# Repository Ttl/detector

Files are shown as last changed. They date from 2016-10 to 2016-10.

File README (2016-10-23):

1 MHz - 10 GHz RF power detector with USB connection.

Based on AD8319 power detector and LPC11U68 microcontroller.

Hardware:

hardware: KiCad files of the board.

Firmware:

lpc_chip_11u6x
lpc_board_detector
detector

Compile with LPCXpresso IDE.

Software:

detector.py: Main code.

ad8139cal.py: Voltage to dBm calibration table.

scalar_vna.py: Scalar network analyzer using two power sensors, two directional couplers and VNA as a signal source. VNA code can be got from: https://github.com/Ttl/vna.

analysis.py: Reflection tracking calibration and plotting the results of scalar network analyzer measurements.

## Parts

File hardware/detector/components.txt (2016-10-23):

http://www.digikey.fi/product-detail/en/analog-devices-inc/AD8319ACPZ-R7/AD8319ACPZ-R7CT-ND/1217637
http://www.digikey.fi/product-detail/en/nxp-semiconductors/LPC11U68JBD64E/568-11003-ND/4557154
http://www.digikey.fi/product-detail/en/nxp-semiconductors/2N7002P,215/568-5818-1-ND/2531105
http://www.digikey.fi/product-detail/en/fairchild-semiconductor/NC7S04P5X/NC7S04P5XCT-ND/965679
http://www.digikey.fi/product-detail/en/peregrine-semiconductor/PE42441A-Z/1046-1108-1-ND/4849858

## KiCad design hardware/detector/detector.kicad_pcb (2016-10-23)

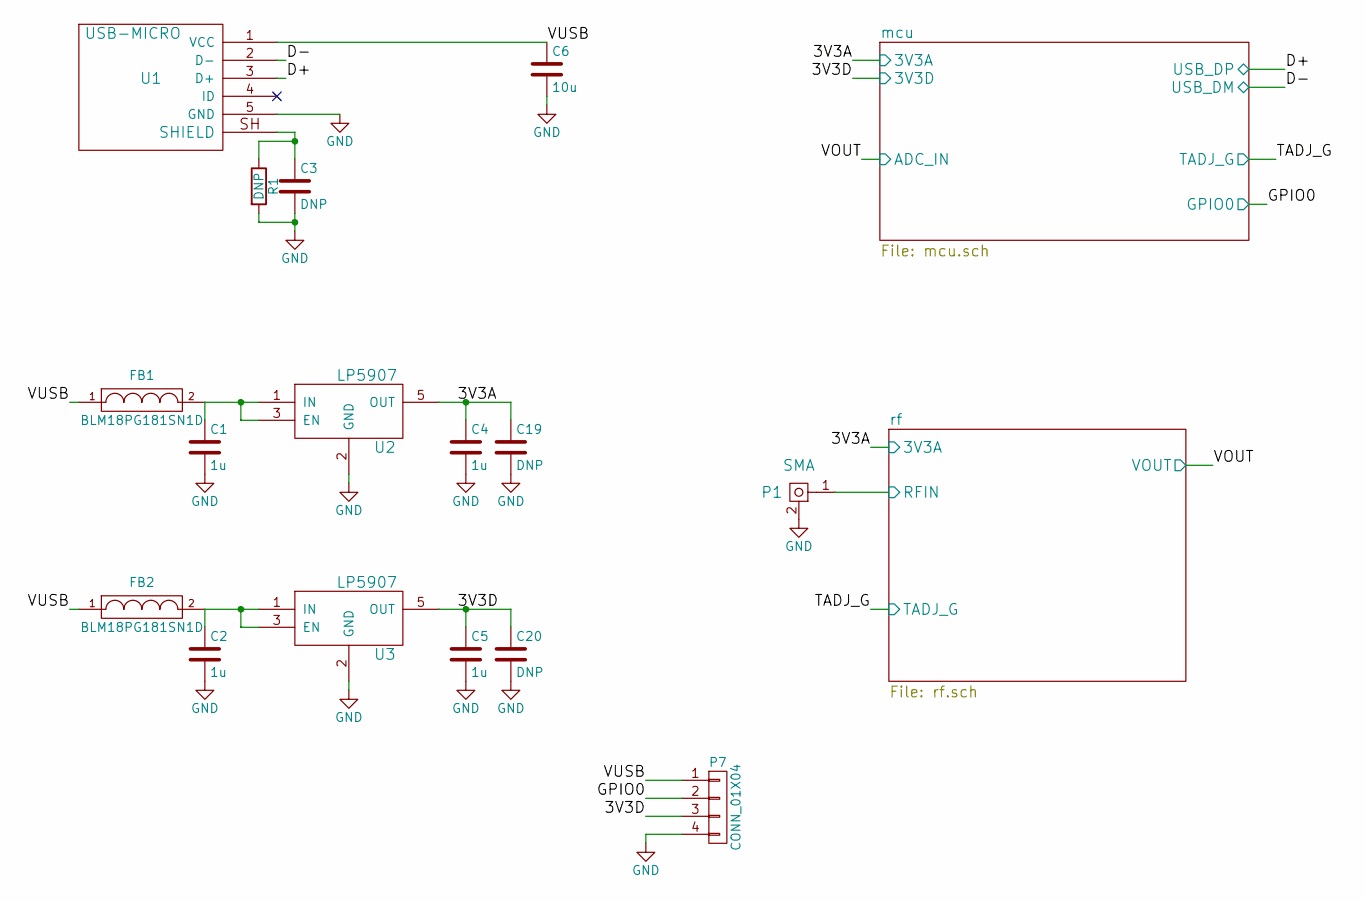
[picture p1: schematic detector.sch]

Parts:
C1, C2, C4, C5: 1u; C_0603b
C3: DNP; C_0402b
C6: 10u; C_0805b
C19, C20: DNP; C_0805b
FB1, FB2: BLM18PG181SN1D; C_0603b
P1: SMA; CONSMA003.062
P7: CONN_01X04; Pin_Header_Straight_1x04
R1: DNP; R_0402b
U1: USB-MICRO; USB_MICRO
U2, U3: LP5907; SOT-23-5

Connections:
/3V3A: C4.1, C19.1, U2.5 (OUT); also elsewhere on the board
/3V3D: C5.1, C20.1, P7.3, U3.5 (OUT); also elsewhere on the board
/D+: U1.3 (D+); also elsewhere on the board
/D-: U1.2 (D-); also elsewhere on the board
/GPIO0: P7.2; also elsewhere on the board
/VUSB: C6.1, FB1.1, FB2.1, P7.1, U1.1 (VCC)
/rf/RFIN: P1.1; also elsewhere on the board
GND: C1.2, C2.2, C3.2, C4.2, C5.2, C6.2, C19.2, C20.2, P1.2, P7.4, R1.2, U1.5 (GND), U2.2 (GND), U3.2 (GND); also elsewhere on the board
unnamed: C1.1, FB1.2, U2.1 (IN), U2.3 (EN)
unnamed: C2.1, FB2.2, U3.1 (IN), U3.3 (EN)
unnamed: C3.1, R1.1, U1.SH (SHIELD)

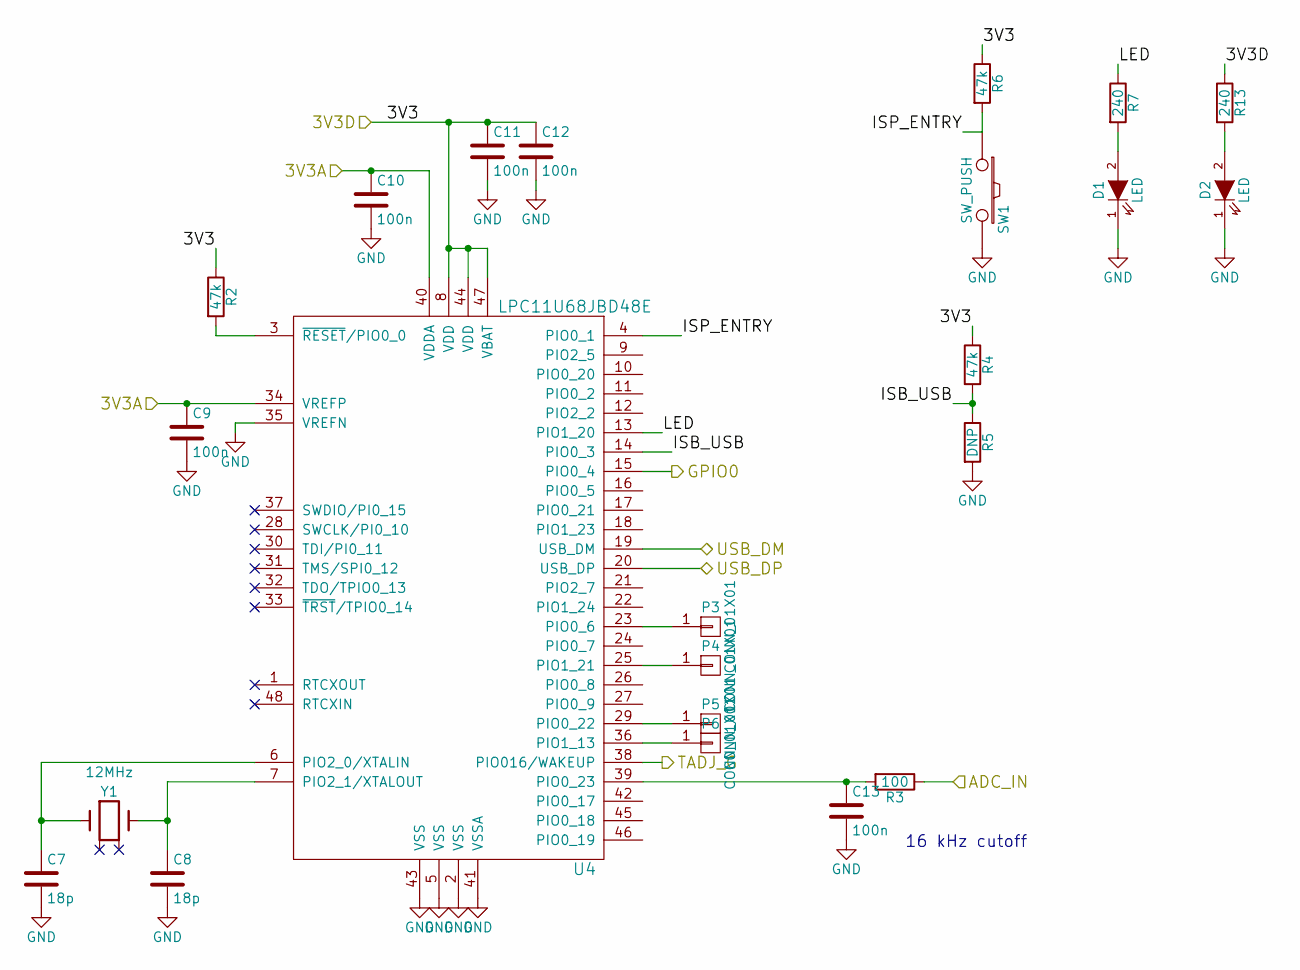
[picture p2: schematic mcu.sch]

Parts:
C7, C8: 18p; C_0402b
C9, C10, C11, C12, C13: 100n; C_0402b
D1, D2: LED; LED_0603
P3, P4, P5, P6: CONN_01X01; TP_1.00
R2, R4, R6: 47k; R_0402b
R3: 100; R_0402b
R5: DNP; R_0402b
R7, R13: 240; R_0402b
SW1: SW_PUSH; EVP-AWBA2A
U4: LPC11U68JBD48E; LQFP-48_7x7mm_Pitch0.5mm
Y1: 12MHz; XTAL_3.2x2.5

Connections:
/3V3A: C9.1, C10.1, U4.34 (VREFP), U4.40 (VDDA); also elsewhere on the board
/3V3D: C11.1, C12.1, R2.1, R4.1, R6.1, R13.1, U4.8 (VDD), U4.44 (VDD), U4.47 (VBAT); also elsewhere on the board
/D+: U4.20 (USB_DP); also elsewhere on the board
/D-: U4.19 (USB_DM); also elsewhere on the board
/GPIO0: U4.15 (PIO0_4); also elsewhere on the board
/TADJ_G: U4.38 (PIO016/WAKEUP); also elsewhere on the board
/VOUT: R3.1; also elsewhere on the board
/mcu/ISB_USB: R4.2, R5.1, U4.14 (PIO0_3)
/mcu/ISP_ENTRY: R6.2, SW1.1, U4.4 (PIO0_1)
/mcu/LED: R7.1, U4.13 (PIO1_20)
GND: C7.2, C8.2, C9.2, C10.2, C11.2, C12.2, C13.2, D1.1 (K), D2.1 (K), R5.2, SW1.2, U4.2 (VSS), U4.5 (VSS), U4.35 (VREFN), U4.41 (VSSA), U4.43 (VSS); also elsewhere on the board
unnamed: C7.1, U4.6 (PIO2_0/XTALIN), Y1.1
unnamed: C8.1, U4.7 (PIO2_1/XTALOUT), Y1.3
unnamed: C13.1, R3.2, U4.39 (PIO0_23)
unnamed: D1.2 (A), R7.2
unnamed: D2.2 (A), R13.2
unnamed: P3.1, U4.23 (PIO0_6)
unnamed: P4.1, U4.25 (PIO1_21)
unnamed: P5.1, U4.29 (PIO0_22)
unnamed: P6.1, U4.36 (PIO1_13)
unnamed: R2.2, U4.3 (~RESET~/PIO0_0)

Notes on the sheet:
16 kHz cutoff

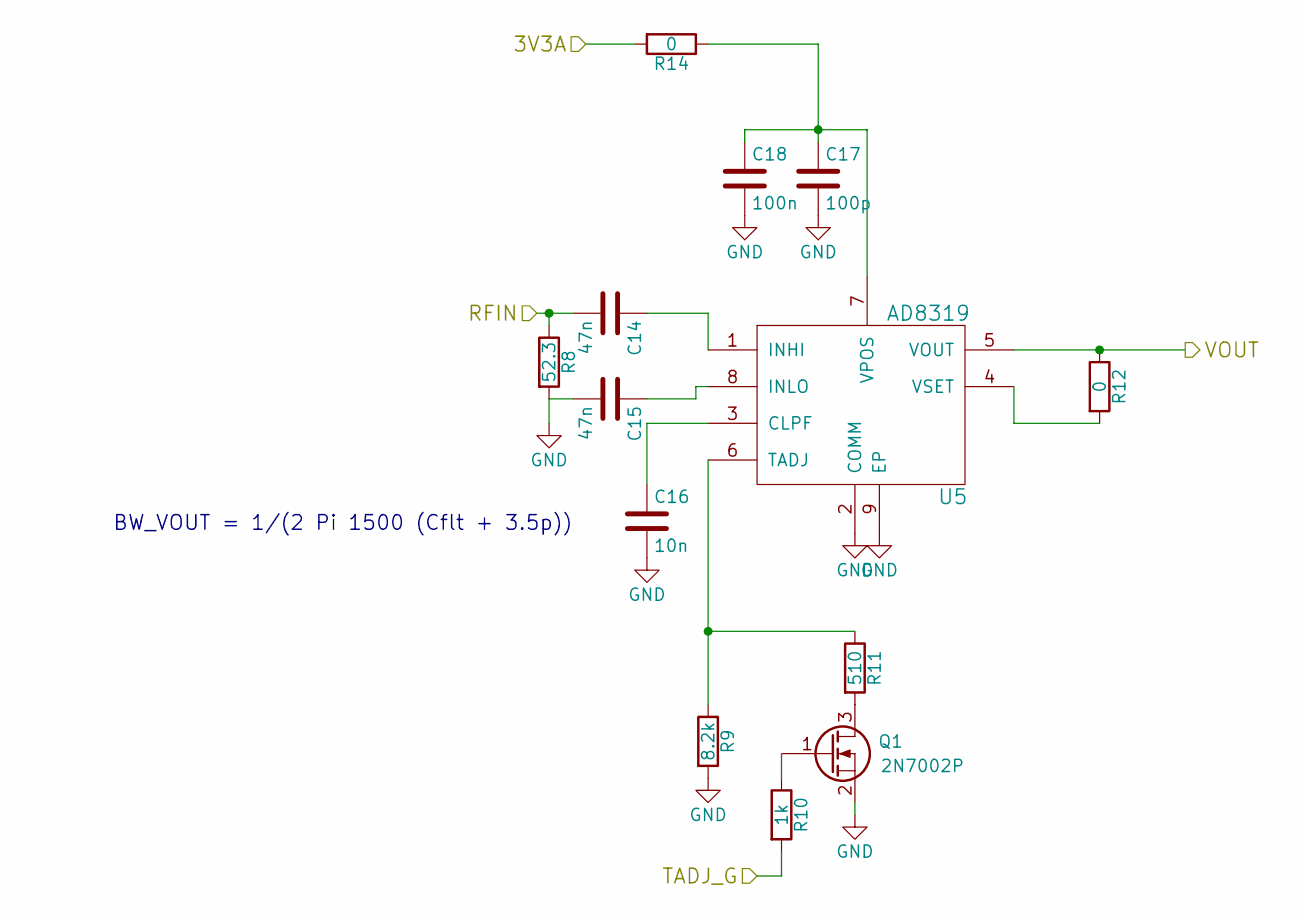
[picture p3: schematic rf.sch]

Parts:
C14, C15: 47n; C_0402b
C16: 10n; C_0402b
C17: 100p; C_0402b
C18: 100n; C_0402b
Q1: 2N7002P; SOT-23
R8: 52.3; R_0402b
R9: 8.2k; R_0402b
R10: 1k; R_0402b
R11: 510; R_0402b
R12, R14: 0; R_0402b
U5: AD8319; LFCSP-8

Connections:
/3V3A: R14.2; also elsewhere on the board
/TADJ_G: R10.2; also elsewhere on the board
/VOUT: R12.1, U5.5 (VOUT); also elsewhere on the board
/rf/RFIN: C14.2, R8.1; also elsewhere on the board
GND: C15.2, C16.2, C17.2, C18.2, Q1.2 (S), R8.2, R9.2, U5.2 (COMM), U5.9 (EP); also elsewhere on the board
unnamed: C14.1, U5.1 (INHI)
unnamed: C15.1, U5.8 (INLO)
unnamed: C16.1, U5.3 (CLPF)
unnamed: C17.1, C18.1, R14.1, U5.7 (VPOS)
unnamed: Q1.1 (G), R10.1
unnamed: Q1.3 (D), R11.2
unnamed: R9.1, R11.1, U5.6 (TADJ)
unnamed: R12.2, U5.4 (VSET)

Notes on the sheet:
BW_VOUT = 1/(2 Pi 1500 (Cflt + 3.5p))

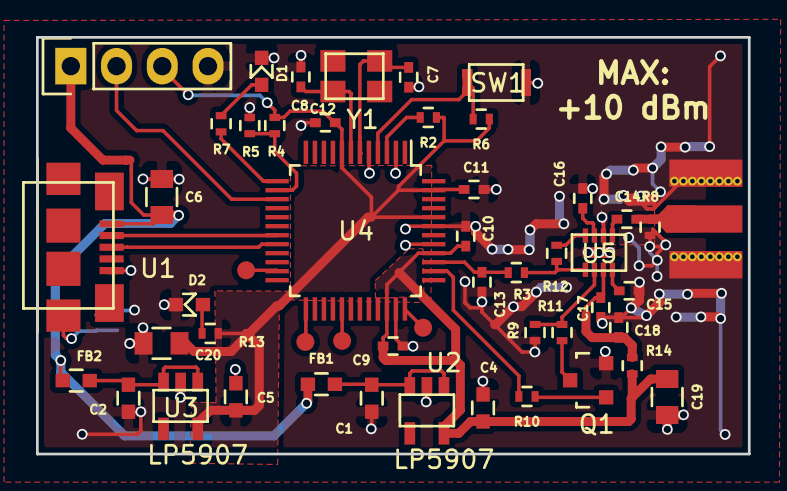
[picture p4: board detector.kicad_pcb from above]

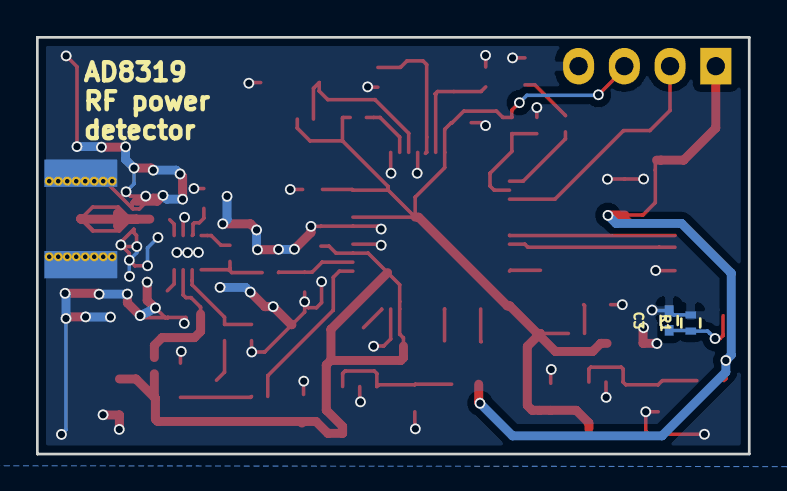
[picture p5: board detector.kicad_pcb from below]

Board: 2 copper layers, 39.5 x 23.2 mm, 52 parts (2 on the bottom side), 34 nets.

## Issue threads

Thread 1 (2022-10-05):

Update readme with compilation guide

Digitelektro, 2022-10-05:
Dear @Ttl

I built the PCB of this nice project, but I got stuck at compiling the firmware. Could you please update the readme with how to build the project, which tools needed for that etc. Or a more easy way (for me) if you could release a binary that I can flash/upload straight to the device.

Thank you!

Digitelektro, 2022-10-05:
Thank you so much! Will try it and get back to you!

Digitelektro, 2022-10-25:
I tried the firmware, it kinda works. I had to change a python script, I think the firmware version of what you sent is older, but I figured out the problem. I had to remove the packet header check from the script.
Thanks!

Closed 2022-10-25.

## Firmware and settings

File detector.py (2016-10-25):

import sys
import serial
import serial.tools.list_ports
from scipy.interpolate import interp1d
from ad8319cal import cal_table

for k in cal_table.keys():
    cal_table[k] = zip(*cal_table[k])

def v_to_dbm(v, freq):
    freq /= 1e6
    cal_freqs = sorted(cal_table.keys())
    x = []
    for f in cal_freqs:
        fx, fy = cal_table[f]
        x.append(interp1d(fy, fx, fill_value='extrapolate')(v))
    return interp1d(cal_freqs, x, fill_value='extrapolate')(freq) + 3.3 #From parallel 50 ohm termination

if __name__ == "__main__":
    if len(sys.argv) != 2:
        print "Give frequency in GHz as argument"
        exit()
    freq = float(sys.argv[1])*1e9
    if freq < 0 or freq > 10e9:
        print "Frequency out of range 0 < freq < 10"
        exit()
    ports = serial.tools.list_ports.comports()
    ser = None
    for dev, name, desc in ports:
        if 'VID:PID=1FC9:0083' in desc:
            try:
                ser = serial.Serial(
                    port=dev,
                    baudrate=1e6,
                    parity=serial.PARITY_NONE,
                    stopbits=serial.STOPBITS_TWO,
                    bytesize=serial.EIGHTBITS,
                    timeout=0.1
                )
                if not ser.isOpen():
                    raise Exception
            except:
                print 'Opening serial port {} failed.'.format(dev)
                raise
    if ser == None:
        raise Exception("Unable to find device")

    #Set T_ADJ
    if freq >= 5.3e9:
        #500 ohm if f > 5.3 GHz
        ser.write('\xf1')
    else:
        #8.2k if f < 5.3 GHz
        ser.write('\xf0')

    while True:
        try:
            x = ord(ser.read(1))
            if x != 0xFF:
                continue
            x = map(ord,ser.read(2))
            if x[0] & 0xF0 != 0x00:
                #Not synchronized
                continue
            y = ((x[0] & 0x0F) << 8) | x[1]
            print v_to_dbm(3.3*y/4095.0, freq)
        except serial.serialutil.SerialException:
            continue
        except OSError:
            continue
        except KeyboardInterrupt:
            print "Exiting"
            break

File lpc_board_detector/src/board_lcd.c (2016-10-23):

/*
 * @brief Manley 11U68 board LCD driver
 *
 * @note
 * Copyright(C) NXP Semiconductors, 2013
 * All rights reserved.
 *
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
 * @par
 * Permission to use, copy, modify, and distribute this software and its
 * documentation is hereby granted, under NXP Semiconductors' and its
 * licensor's relevant copyrights in the software, without fee, provided that it
 * is used in conjunction with NXP Semiconductors microcontrollers.  This
 * copyright, permission, and disclaimer notice must appear in all copies of
 * this code.
 */

#include "board.h"

/*****************************************************************************
 * Private types/enumerations/variables
 ****************************************************************************/

/* LCD (SPI_CS) port and pin */
#define LCDCS_PORT          0
#define LCDCS_PIN           2

/* 100nS SPI clock */
#define LCDSSP_BITRATE      (25000000)

/* SSP device mapped to LCD */
#define LCD_SSP             LPC_SSP0

/* Horizontal and vertical sizes of the LCD */
#define LCD_HORIZ_SIZE      320
#define LCD_VERT_SIZE       240

/* Flag indicating portrait or landscape orientation */
static bool orientationPortrait;
static uint8_t cont_mem;

/* Window data */
static const struct {
	uint16_t width;
	uint16_t height;
} lcd_size[] = {
	{LCD_HORIZ_SIZE, LCD_VERT_SIZE},/* Landscape mode */
	{LCD_VERT_SIZE, LCD_HORIZ_SIZE},/* Portrait mode */
};
static uint16_t line_buffer[LCD_HORIZ_SIZE + 1];
static const uint8_t InitLCD_dat[] = {
	/* Data length , Command, Data */

	/* Power control B */
	3,  0xCF, 0x00, 0xC1, 0x30,
	/* Power on sequence control */
	4,  0xED, 0x64, 0x03, 0x12, 0x81,
	/* Driver timing control A */
	3,  0xE8, 0x85, 0x10, 0x7A,
	/* Power control A */
	5,  0xCB, 0x39, 0x2C, 0x00, 0x34, 0x02,
	/* Pump ratio control */
	1,  0xF7, 0x20,
	/* Driver timing control B */
	2,  0xEA, 0x00, 0x00,
	/* Power control */
	1,  0xC0, 0x1B,
	/* Power control */
	1,  0xC1, 0x01,
	/* VCM control */
	2,  0xC5, 0x45, 0x25,
	/* VCM control2 */
	1,  0xC7, 0xB7,
	/* Memory Access Control */
	1,  0x36, 0x28,
	/*Pixel Format Set */
	1,  0x3A, 0x55,
	/*Frame Rate Control */
	2,  0xB1, 0x00, 0x1A,
	/* Display Function Control */
	2,  0xB6, 0x0A, 0x82,
	/* 3Gamma Function Disable */
	1,  0xF2, 0x00,
	/* Gamma curve selected */
	1,  0x26, 0x01,
	/* Set Gamma */
	15, 0xE0, 0x0F, 0x2A, 0x28, 0x08, 0x0E, 0x08, 0x54, 0xA9, 0x43, 0x0A, 0x0F, 0x00, 0x00, 0x00, 0x00,
	/* Set Gamma */
	15, 0xE1, 0x00, 0x15, 0x17, 0x07, 0x11, 0x06, 0x2B, 0x56, 0x3C, 0x05, 0x10, 0x0F, 0x3F, 0x3F, 0x0F,
	/* Address Column set */
	4,  0x2A, 0x00, 0x00, 0x01, 0x3F,
	/* Address Page set */
	4,  0x2B, 0x00, 0x00, 0x00, 0xEF,
	/* Sleep OUT */
	0,  0x11,
	/* Display ON */
	0,  0x29,
};

/*****************************************************************************
 * Public types/enumerations/variables
 ****************************************************************************/

/*****************************************************************************
 * Private functions
 ****************************************************************************/

/* Read data to LCD controller via SPI */
static uint16_t Board_LCD_ReadData(void)
{
	/* FIXME: Implement later */
	return 0;
}

/* Initialize SPI interface for board */
static void Board_LCDSSP_Init(void)
{
	/* Enable SSP clocking and setup SSP defaults */
	Chip_SSP_Init(LCD_SSP);

	/* 8 bits data, SPI0 mode */
	Chip_SSP_Set_Mode(LCD_SSP, SSP_MODE_MASTER);
	Chip_SSP_SetFormat(LCD_SSP, SSP_BITS_9, SSP_FRAMEFORMAT_SPI, SSP_CLOCK_CPHA0_CPOL0);

	/* Set SPI clock rate for LCD controller */
	Chip_SSP_SetBitRate(LCD_SSP, LCDSSP_BITRATE);

	/* Enable SSP */
	Chip_SSP_Enable(LCD_SSP);
}

/* Initialize the LCD Panel with startup values */
static void Board_LCDPanel_Init(void)
{
	int i, len = 0;
	for (i = 0; i < sizeof(InitLCD_dat) / sizeof(uint8_t); i += 2 + len) {
		len = InitLCD_dat[i];
		Board_LCD_WriteData(InitLCD_dat[i + 1], &InitLCD_dat[i + 2], len);
	}
}

/*****************************************************************************
 * Public functions
 ****************************************************************************/

/* Initialize LCD controller */
void Board_LCD_Init(bool portrait)
{
	volatile int i;
	/* LCD_CS (SPI_CS) mapped to PIO0_2, use GPIO to control frame */
	Chip_IOCON_PinMuxSet(LPC_IOCON, LCDCS_PORT, LCDCS_PIN,
						 (IOCON_FUNC0 | IOCON_MODE_INACT | IOCON_DIGMODE_EN));
	/* BLC mapped to PIO1_20, not used */

	/* Setup GPIO for LCD CS to output, initial LCD CS state is high */
	Chip_GPIO_SetPinDIROutput(LPC_GPIO, LCDCS_PORT, LCDCS_PIN);

	/* Initialize SPI for board LCD controller */
	Board_LCDSSP_Init();

	/* Save orientation */
	orientationPortrait = portrait;

	/* Initial LCD */
	Board_LCDPanel_Init();

	if (portrait) {	/* set to portrait mode */
		uint8_t ch = 0x8;
		Board_LCD_WriteData(0x36, &ch, 1);
	}
	for (i = 0; i < 0xFFFFF; i++) {}
}
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

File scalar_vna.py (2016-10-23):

import matplotlib.pyplot as plt
import numpy as np
from detector import *
from vna import *
import pickle

lo_set = False
lo_pll = MAX2871(2)
source_pll = MAX2871(3)

def measure(sers, device, freqs, apwr=1):
    global lo_set
    real_freqs = []
    samples = []
    for freq in freqs:
        #Set T_ADJ
        #for ser in sers:
        #    if freq >= 5.3e9:
        #        #500 ohm if f > 5.3 GHz
        #        ser.write('\xf1')
        #    else:
        #        #8.2k if f < 5.3 GHz
        #        ser.write('\xf0')

        source_freq = freq
        ref_freq = 19.2e6

        select_filter(device, source_freq)

        real_freqs.append(source_pll.freq_to_regs(source_freq, ref_freq, apwr=apwr))

        if not lo_set:
            lo_pll.freq_to_regs(source_freq, ref_freq, apwr=0)
            lo_pll.to_device(device)
            time.sleep(20e-3)
            lo_pll.to_device(device)
            lo_set = True
            source_pll.to_device(device)
            time.sleep(20e-3)
        source_pll.to_device(device)

        #print source_power(device, source_freq)

        ps = [None, None]
        for e,ser in enumerate(sers):
            ser.reset_input_buffer()
            while True:
                try:
                    x = ord(ser.read(1))
                    if x != 0xFF:
                        continue
                    x = map(ord,ser.read(2))
                    if x[0] & 0xF0 != 0x00:
                        #Not synchronized, try again
                        continue
                    y = ((x[0] & 0x0F) << 8) | x[1]
                    ps[e] = (v_to_dbm(3.3*y/4095.0, freq))
                except KeyboardInterrupt:
                    print "Exiting"
                    break
                break
        print ps[1]-ps[0],ps[0],ps[1]
        samples.append(ps[1]-ps[0])
    return real_freqs, samples

if __name__ == "__main__":

    #Find VNA to use as a source
    source = None
    device = usb.core.find(idVendor=0x1d50, idProduct=0x6099)
    if device == None:
        print "VNA not found"
        exit(0)
    print "Found VNA"

    device.set_configuration()


    #Initialize VNA
    device.ctrl_transfer(0x40, 4, 0, (1 << 0) | (1 << 2) | (0 << 3)) #Signal, PA on
    write_att(device, 0)
    select_mixer_input(device, 'rx1')
    select_port(device, 2)

    sers = []
    ports = serial.tools.list_ports.comports()
    for dev, name, desc in ports:
        if 'VID:PID=1FC9:0083' in desc:
            try:
                ser = serial.Serial(
                    port=dev,
                    baudrate=1e6,
                    parity=serial.PARITY_NONE,
                    stopbits=serial.STOPBITS_TWO,
                    bytesize=serial.EIGHTBITS,
                    timeout=0.1
                )
                if not ser.isOpen():
                    raise Exception
                sers.append(ser)
            except:
                print 'Opening serial port {} failed.'.format(dev)
                raise
    if len(sers) < 2:
        raise Exception("Unable to find power detectors. Found {}.".format(len(sers)))

    freqs = np.linspace(100e6, 5.999e9, 600)
    try:
        real_freqs, samples = measure(sers, device, freqs)
        print np.mean(samples)

        with open('response.p', 'w') as f:
            pickle.dump((real_freqs, samples), f)
        plt.plot(real_freqs, samples)
        plt.show()
    finally:
        device.ctrl_transfer(0x40, 5, 0, (1 << 0) | (1 << 2) | (1 << 3)) #Signal, PA off
